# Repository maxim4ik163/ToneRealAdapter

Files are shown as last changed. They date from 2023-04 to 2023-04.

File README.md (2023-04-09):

# ToneReal Guitar Adapter
## RU
Самодельный гитарный адаптер для игры в Rocksmith на базе CMedia CM6327A, которая имеет возможность конфигурации VID/PID через EEPROM, что позволяет использовать её как оригинальный кабель на PlayStation, Xbox и ПК.

[Даташит](https://github.com/maxim4ik163/ToneRealAdapter/blob/main/Datasheets/CM6327A.pdf) на этот чип не содержит принципиальной схемы, поэтому пришлось воссоздавать её по [фотографиям](https://github.com/maxim4ik163/ToneRealAdapter/tree/main/Reference_PCB's) плат от различных USB-микрофонов на базе CM6327A (Blue snowball ice, Trust Buzz, Bird UM-1, DEXP BK-20 и т.д.).
Для того чтобы быть уверенным в принципиальной схеме я купил DEXP BK-20 с типовой платой YFT261764 на базе CM6327A.

Проект содержит 3 версии платы:
  - ToneReal_Adapter_v1.1 - уменьшенная версия с керамическими конденсаторами (ближе к оригинальному кабелю RGA).
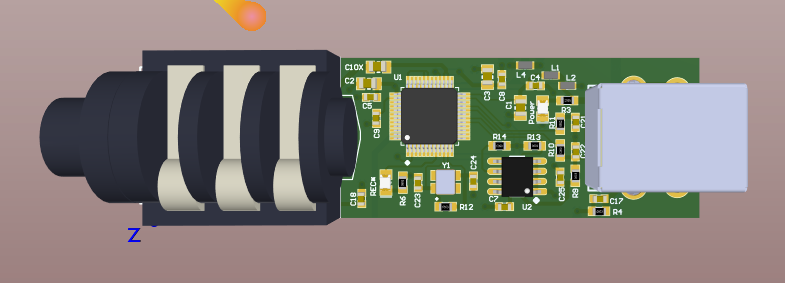
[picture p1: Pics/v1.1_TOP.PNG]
  

  - ToneReal_Adapter_v1.0 - увеличенная версия, с электролитическими SMD конденсаторами (реплика платы YFT261764).
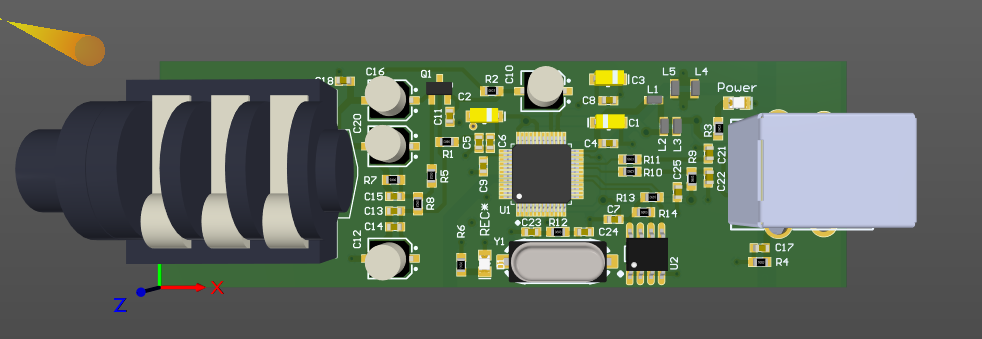
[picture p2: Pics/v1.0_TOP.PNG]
  

  - ToneReal_Adapter_DIY - однослойная плата для изготовления методом ЛУТ.
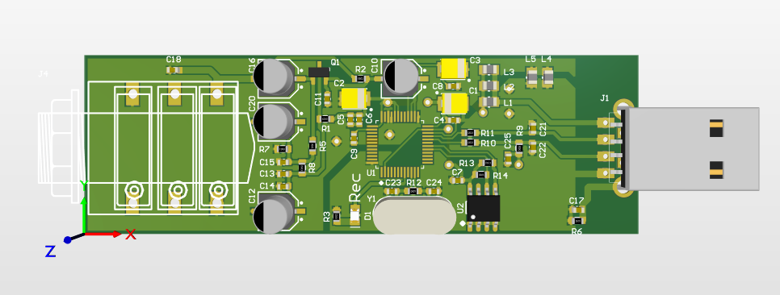
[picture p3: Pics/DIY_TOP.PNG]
  

  В версиях 1.0 и 1.1 предусмотрены посадочные места для разъема USB type-A для подключения адаптера непосредственно в устройство или гнездового разъема type-B для использования с кабелем. Также на платах есть отверстия для стяжек, если вы захотите припаять гитарный кабель напрямую к плате, а не использовать джек 6.35.

## Сборка
1. Соберите желаемую версию в соответствии с BOM (или используйте готовую плату от микрофона на базе CM6327A).
2. Запрограммируйте EEPROM с прикрепленным [дампом](https://github.com/maxim4ik163/ToneRealAdapter/blob/main/EEPROM/DUMP%20RGA.bin) (например, используя программатор CH341A).
3. Если все сделано правильно, VID/PID устройства должен [измениться](https://github.com/maxim4ik163/ToneRealAdapter/blob/main/Pics/VID_PID.png) на 12BA 00FF.
4. Собирайте Олимпийский в Rocksmith :)

## Тесты
  - PlayStation 5 с PS4 Rocksmith 2014 Remastered (*примечание: версия для PS4 имеет проблему с задержкой вывода звука на PS5 через HDMI как и с оригинальным кабелем. Используйте беспроводную гарнитуру Pulse 3D или Dualsense для вывода звука*) - [ссылка](https://github.com/maxim4ik163/ToneRealAdapter/blob/main/Test_videos/PS5_test.MOV)
  - XBOX360 с Rocksmith 2014 - [ссылка](https://github.com/maxim4ik163/ToneRealAdapter/blob/main/Test_videos/XBOX360_test.MOV)
  - ПК с Rocksmith 2014 Remastered - [ссылка](https://github.com/maxim4ik163/ToneRealAdapter/blob/main/Test_videos/PC_test.MOV)

### Дисклеймер
> Из-за необходимости долгого ожидания CM6327A с Алиэкспресс, производства печатной платы и отсутсвия скидок на Rocksmith в PSN я не выдержал и купил с рук оригинальный кабель с игрой :) Зато это позволило мне сравнить оригинальный кабель и самодельный друг с другом: они идентичны по звучанию и задержкам. Так что в правильности схемы я уверен на 99.9%.

## En
DIY Rocksmith guitar adapter based on CMedia CM6327A  USB Single-Chip Audio Solution for Mono Microphone. VID/PID/product and manufacture strings of this chip can be configured by EEPROM, that allows to use it as original cable on PlayStation, Xbox and PC.

[Datasheet](https://github.com/maxim4ik163/ToneRealAdapter/blob/main/Datasheets/CM6327A.pdf) for this chip doesn't contain schematics, so I used PCB from various USB-microphones based on CM6327A as [reference](https://github.com/maxim4ik163/ToneRealAdapter/tree/main/Reference_PCB's) (Blue snowball ice, Trust Buzz, Bird UM-1 DEXP BK-20 etc).
To check my schematics made by photos of PCBs, i bought DEXP BK-20 with PCB YFT261764 and checked all the traces.

Project contains 3 version of PCB:
 - ToneReal_Adapter_v1.1 - small version (closer to original RGA cable).
 v1.1
 - ToneReal_Adapter_v1.0 - bigger version, uses ECAP (closer to reference boards).
 v1.1
 - ToneReal_Adapter_DIY - one layer PCB for homemade.
 v1.1

 Versions 1.0 and 1.1 has footprints for USB Type-A male connector to mount adapter directly to device or Type-B female connector for use with cable. Also boards have holes for zipties, if you want to solder guitar cable directly to PCB and not use 6.35 jack.

## Assembly
1. Assemble the desired version according to the BOM (or get PCB from mic with CM6327A).
2. Program the EEPROM with the attached [dump](https://github.com/maxim4ik163/ToneRealAdapter/blob/main/EEPROM/DUMP%20RGA.bin) (as exemple using CH341A).
3. If everything is done correctly, the VID/PID of the device should [change](https://github.com/maxim4ik163/ToneRealAdapter/blob/main/Pics/VID_PID.png) to 12BA 00FF.
4. Plug and enjoy :)

## Tests
 -  PlayStation 5 with PS4 Rocksmith 2014 Remastered (*note: PS4 version has output delay issue on PS5 via HDMI with original/ToneReal cable. Use Pulse 3D Wireless Headset or Dualsense for audio output*)  - [link](https://github.com/maxim4ik163/ToneRealAdapter/blob/main/Test_videos/PS5_test.MOV)
 -  XBOX360 with Rocksmith 2014 - [link](https://github.com/maxim4ik163/ToneRealAdapter/blob/main/Test_videos/XBOX360_test.MOV)
 -  PC with Rocksmith 2014 Remastered - [link](https://github.com/maxim4ik163/ToneRealAdapter/blob/main/Test_videos/PC_test.MOV)

### Disclaimer
> I did not assemble this circuit board because during the development  I tested this concept on a board from a USB microphone. And because of the need for a long wait for chip from Aliexpress, production of PCB and PSN game discount I purchased the original cable with game :) 
But this allowed me to compare them with each other: they are identical in sound and delays. So I am 99.9% sure that the circuit is correct.

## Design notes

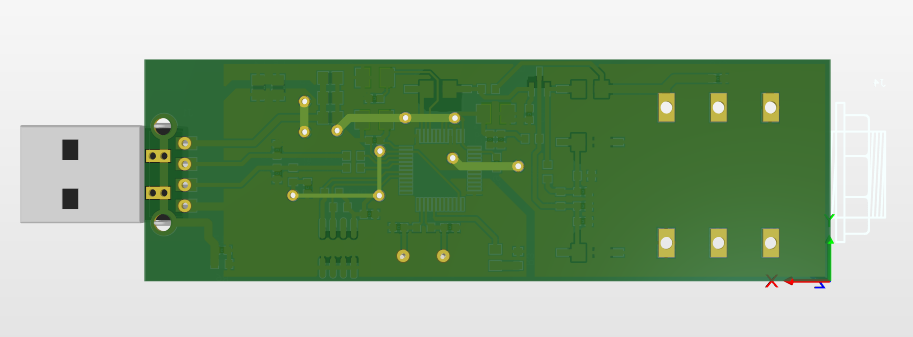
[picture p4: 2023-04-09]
Pics/DIY_BOTTOM.PNG

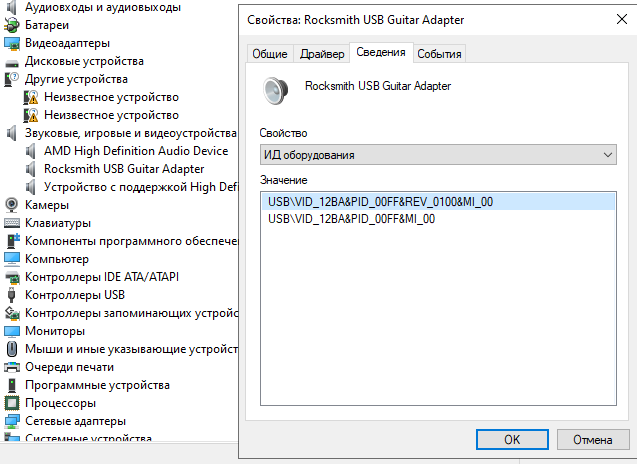
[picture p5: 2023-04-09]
Pics/VID_PID.png

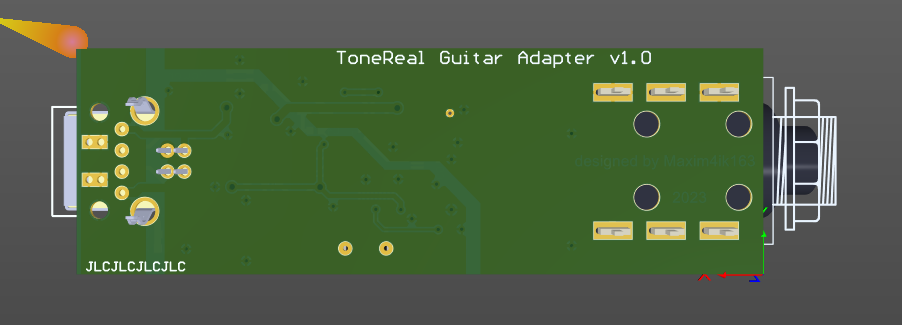
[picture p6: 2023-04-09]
Pics/v1.0_BOTTOM.PNG

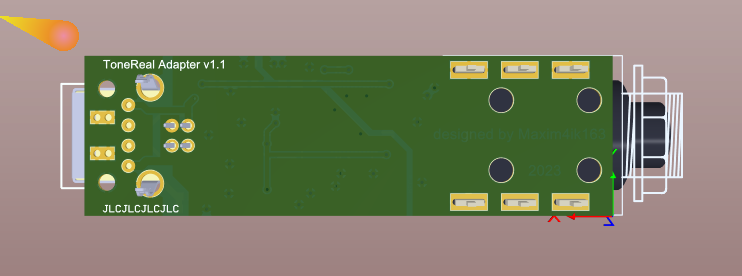
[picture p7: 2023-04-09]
Pics/v1.1_BOTTOM.PNG

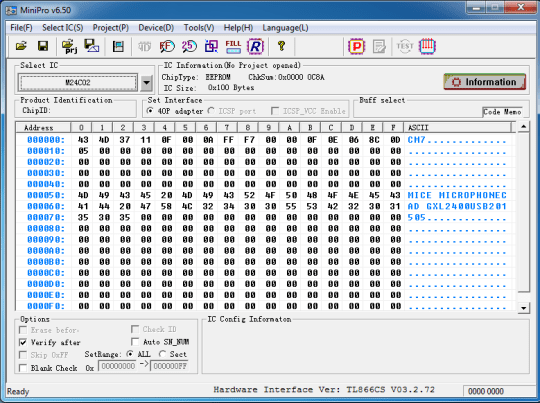
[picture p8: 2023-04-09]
Reference_PCB's/2 Mics_ An over-engineered solution – Exfil.co_files/Screen-Shot-2018-05-16-at-11.01.05-AM.png

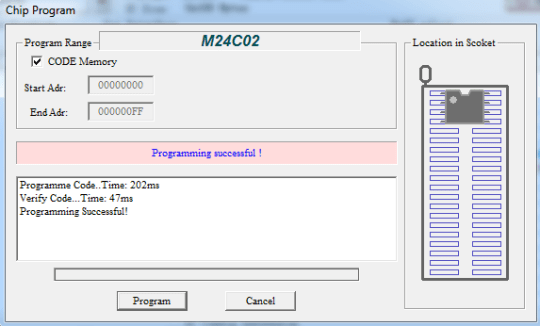
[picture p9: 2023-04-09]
Reference_PCB's/2 Mics_ An over-engineered solution – Exfil.co_files/Screen-Shot-2018-05-16-at-11.03.06-AM.png

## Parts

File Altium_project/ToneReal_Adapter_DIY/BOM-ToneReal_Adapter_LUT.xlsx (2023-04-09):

Designator | Comment | Quantity | Description | Footprint | LibRef
C1, C2, C3 | 10uF/16V | 3 | Capacitor (Semiconductor SIM Model) | TECAP SMD_B (IPC-3528) | Cap Semi
C4 | ? | 1 | Capacitor (Semiconductor SIM Model) | CERCAP SMD0603L (IPC1608L) | Cap Semi
C5, C7, C8, C9, C14, C15 | 1uF | 6 | Capacitor (Semiconductor SIM Model) | CERCAP SMD0603L (IPC1608L) | Cap Semi
C6, C11, C13, C18, C21, C22, C25 | 100pF | 7 | Capacitor (Semiconductor SIM Model) | CERCAP SMD0603L (IPC1608L) | Cap Semi
C10 | 1uF/50V | 1 | Polarized Capacitor (Surface Mount) | ECAP SMD KVE 5.0x5.3 | Cap Pol3
C12 | 47uF/6.3V | 1 | Polarized Capacitor (Surface Mount) | ECAP SMD KVE 5.0x5.3 | Cap Pol3
C16 | 4.7uF/25V | 1 | Polarized Capacitor (Surface Mount) | ECAP SMD KVE 5.0x5.3 | Cap Pol3
C17 | 4.7nF | 1 | Capacitor (Semiconductor SIM Model) | CERCAP SMD0603L (IPC1608L) | Cap Semi
C20 | 22uF/6.3V | 1 | Polarized Capacitor (Surface Mount) | ECAP SMD KVE 5.0x5.3 | Cap Pol3
C23, C24 | 20pF | 2 | Capacitor (Semiconductor SIM Model) | CERCAP SMD0603L (IPC1608L) | Cap Semi
D1 | PLAY/REC | 1 | Typical INFRARED GaAs LED | SMDLED_0805 | LED0
J1 | USB_A | 1 |  | USBA_1PLAG | USB
J4 | JACK6.3_MONO_R | 1 | JACK6.3_MONO_R | JACK6.3 | JACK6.3_MONO_R
L1, L2, L3, L4, L5 | BLM21PG221SN1 | 5 |  | BLM21P (0805 size) | INDUCT
Q1 | BC846B/BC850 | 1 | NPN Bipolar Transistor | SOT_23 | BC846B
R1 | 150 | 1 | Resistor | RES smd0603 (IPC-1608) | RES
R2 | 680 | 1 | Resistor | RES smd0603 (IPC-1608) | RES
R3 | 1k | 1 | Resistor | RES smd0603 (IPC-1608) | RES
R5, R7 | 100k | 2 | Resistor | RES smd0603 (IPC-1608) | RES
R6 | 1MOm | 1 | Resistor | RES smd0603 (IPC-1608) | RES
R8 | 51k3 | 1 | Resistor | RES smd0603 (IPC-1608) | RES
R9 | 1k5 | 1 | Resistor | RES smd0603 (IPC-1608) | RES
R10, R11 | 22 | 2 | Resistor | RES smd0603 (IPC-1608) | RES
R12 | 1M | 1 | Resistor | RES smd0603 (IPC-1608) | RES
R13, R14 | 2k2 | 2 | Resistor | RES smd0603 (IPC-1608) | RES
U1 | CM6327A | 1 | CM6327 | QFP50P900X900X160-48N | CM6327_1
U2 | 24C02 | 1 |  | SOIC-8 | 24C02
Y1 | 12MHz | 1 | 3225 | HC-49/U3H (KX-3H) | TSX-3225

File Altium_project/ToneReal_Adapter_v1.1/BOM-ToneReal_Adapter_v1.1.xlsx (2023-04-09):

Designator | Comment | Quantity | Description | Footprint | LibRef
C1, C2, C3 | 22uF/6.3V | 3 | Capacitor (Semiconductor SIM Model) | CERCAP SMD0805 (IPC-2012) | Cap Semi
C4, C5, C7, C8 | 100nF | 4 | Capacitor (Semiconductor SIM Model) | CERCAP SMD0603L (IPC1608L) | Cap Semi
C9 | 1uF | 1 | Capacitor (Semiconductor SIM Model) | CERCAP SMD0603L (IPC1608L) | Cap Semi
C10X | 1uF | 1 | Capacitor (Semiconductor SIM Model) | CERCAP SMD0805 (IPC-2012) | Cap Semi
C17 | 4.7nF | 1 | Capacitor (Semiconductor SIM Model) | CERCAP SMD0603L (IPC1608L) | Cap Semi
C18, C21, C22, C25 | 100pF | 4 | Capacitor (Semiconductor SIM Model) | CERCAP SMD0603L (IPC1608L) | Cap Semi
C23, C24 | 20pF | 2 | Capacitor (Semiconductor SIM Model) | CERCAP SMD0603L (IPC1608L) | Cap Semi
J1 | USB_A | 1 |  | USBA_1PLAG_NO_3D | USB
J2 | USB_B | 1 |  | USB-B | USB
J4 | ST-020/7-0085 | 1 | JACK6.3_MONO_R | JACK6.3 - duplicate | JACK6.3_MONO_R
L1, L2, L4 | BLM21PG221SN1 | 3 |  | BLM18P (0603L SIZE) | INDUCT
Power |  | 1 | Typical INFRARED GaAs LED | SMDLED_0805 | LED0
R3 | 4k7 | 1 | Resistor | RES smd0603 (IPC-1608) | RES
R4, R12 | 1M | 2 | Resistor | RES smd0603 (IPC-1608) | RES
R6 | 1k | 1 | Resistor | RES smd0603 (IPC-1608) | RES
R9 | 1k5 | 1 | Resistor | RES smd0603 (IPC-1608) | RES
R10, R11 | 22 | 2 | Resistor | RES smd0603 (IPC-1608) | RES
R13, R14 | 2k2 | 2 | Resistor | RES smd0603 (IPC-1608) | RES
REC* | REC* | 1 | Typical INFRARED GaAs LED | SMDLED_0805 | LED0
U1 | CM6327A | 1 | CM6327 | QFP50P900X900X160-48N | CM6327_1
U2 | 24C02 | 1 |  | SOIC-8 | 24C02
Y1 |  | 1 | 3225 | XTAL_3225 | TSX-3225

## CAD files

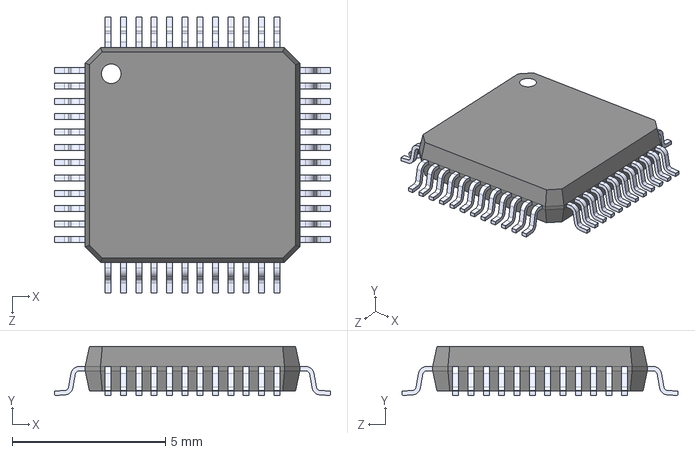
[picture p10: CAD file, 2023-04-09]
Altium_project/3D_models/S9S12C64J2CFAE.STEP
9.00 x 1.60 x 9.00 mm

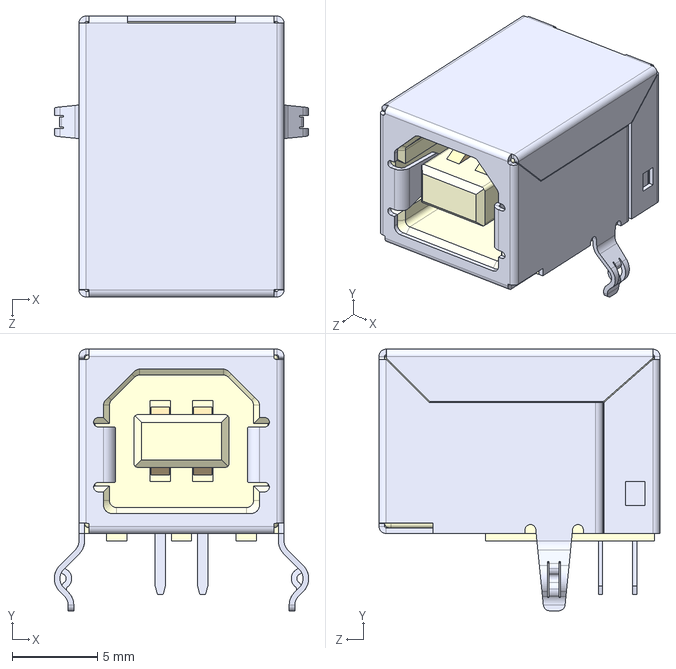
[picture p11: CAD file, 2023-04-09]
Altium_project/3D_models/SS-52300-001--3DModel-STEP-56544.STEP
14.9 x 15.4 x 16.5 mm
